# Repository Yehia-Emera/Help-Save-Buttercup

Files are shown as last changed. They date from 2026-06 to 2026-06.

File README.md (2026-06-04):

# HELP. SAVE BUTTERCUP! 🌸🫧🟢
**Automated Ball Sorting & Shooting Recycling System**

This repository contains the mechanical, electrical, and software files for our MCT231 Basics of Mechatronics final project at the Faculty of Engineering, Ain Shams University (UG2023).

## 📌 Project Overview
"Help. Save Buttercup!" is a closed-loop mechatronic system that autonomously receives, color-sorts, shoots, and recycles balls through a continuous cycle. The system integrates servo actuation, stepper motor control, IR sensing, color detection, and Bluetooth communication, all coordinated across dual Arduino Uno controllers powered by a single shared PSU.

## 🎮 The Game Theme
To make the system interactive, we integrated a Powerpuff Girls game loop. Mojo Jojo has kidnapped Buttercup, and players must help Blossom and Bubbles save her before a 2-minute timer expires. 
* Players shoot sorted balls into designated targets.
* Questions and choices appear via a Bluetooth terminal.
* **Blossom (Red Ball):** Multiplication questions. Awards 2 HP damage to Mojo Jojo on a correct answer.
* **Bubbles (Blue Ball):** Addition questions. Awards 1 HP damage on a correct answer.
* **Goal:** Deplete Mojo Jojo's 10 HP bar to win!

## ⚙️ System Architecture
The repository is organized by engineering discipline rather than subsystem, as components are shared across the dual microcontrollers.

### Hardware Specifications
* **Controllers:** 2x Arduino Uno
* **Color Detection:** TCS3200 Color Sensor
* **Sorting Actuator:** SG90 Servo (with 15g PLA+ custom claw)
* **Turnstile:** PLA+ (40mm radius, 120° sweep)
* **Shooting Base:** Stepper Motor (45° rotation)
* **Lifting Mechanism:** Servo arm (90° vertical lift over 40cm)
* **Sensors:** 5x IR Sensors (sorter, lifter x2, box x2)
* **Comms & UI:** HC-06 Bluetooth Module, 16x2 I2C LCD

## 📂 Repository Structure
* `/CAD_Assembly` - Autodesk Inventor files and 3D printable STLs (turnstile, claw, base).
* `/Code` - Arduino `.ino` files for both the master and slave controllers.
* `/Electronics` - Circuit wiring schematics and pinout diagrams.
* `/Documentation` - System flowchart, block diagram, and the final A0 presentation poster.

## 👥 Team Members
* Yehia Mohammed Fawzy (24P0322)
* Mowahed Mohamed Mohamed (24P0302)
* Ahmed Mohammed Youssef (24P0079)
* Abdulrahman Khaled Ahmed (24P0465)
* Gana Khalid Abdelwahab (24P0251)

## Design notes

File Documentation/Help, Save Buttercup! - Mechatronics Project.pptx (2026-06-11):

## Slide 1

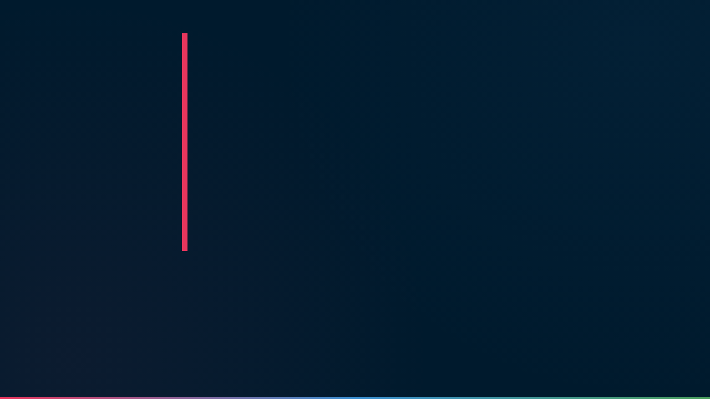
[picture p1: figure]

HELP, SAVE
BUTTERCUP!

Mechatronic Ball Sorting & Game Ecosystem

Engineering Project Defense

MCT231 · Faculty of Engineering · Ain Shams University

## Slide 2

Introduction

"Help. Save Buttercup!" is an interactive, gamified mechatronic toy that turns standard arithmetic practice into a.. physical rescue mission.

This game tackles the loss in engagement children experience when learning math through repetitive paper worksheets and assignments by transforming the process into a rewarding play experience.

Mowahed Mohamed Mohamed Mohamed 24P0302
Ahmed Mohammed Youssef Ibrahim Eidarous 24P0079 Abdulrahman Khaled Ahmed Elish 24P0465
Gana Khalid Abdelwahab 24P0251
Yehia Mohammed Fawzy Ebrahim Emera 24P0322

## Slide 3

User Research

Children in the age range from 2 to 10 years old require physical interaction to maintain focus on educational tasks; additionally, having a clear goal that lets them know what success is like minimizes frustration and off-task behaviors.

After careful considerations we decided to map specific math operations to physical ball colors (Blue for Addition, Red for Multiplication) and made a clear target goal ,that is to deplete Mojo JoJo 10 Hp Bar, to the feedback loop to maximize retention and engagement.

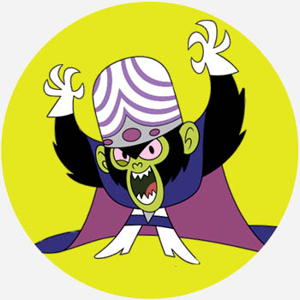
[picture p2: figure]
Mojo Jojo | Fictional Characters | Dictionary.com
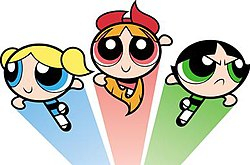
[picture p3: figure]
The Powerpuff Girls - Wikipedia

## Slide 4

Design Challenge

Engineering a fully autonomous, closed-loop mechanical system that seamlessly synchronizes with a digital educational interface, without requiring adult intervention to reset.

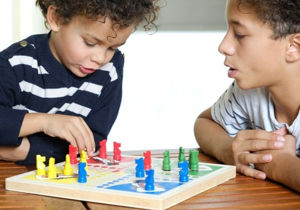
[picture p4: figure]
Educational games and toys for kids: Are they effective?

If a toy jams or requires constant manual reloading, the child's immersion breaks and the educational value is lost. A self-recycling loop ensures the user can focus entirely on the math challenges and the narrative.

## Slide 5

Toy Description and Functionality

Mojo Jojo's Hostage Situation

Townsville's toughest fighter, Buttercup, has been kidnapped by Mojo Jojo. The city's only hope lies in an automated defense system coordinated by her sisters, Blossom and Bubbles.

This project transforms a traditional mechatronic ball-sorting task into a narrative-driven game experience. Players must engage with the system to solve mathematical challenges and deplete Mojo Jojo’s health points through hardware-software synergy.

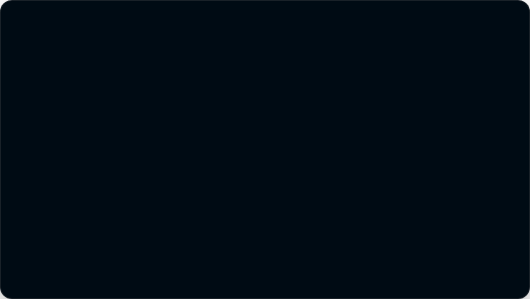
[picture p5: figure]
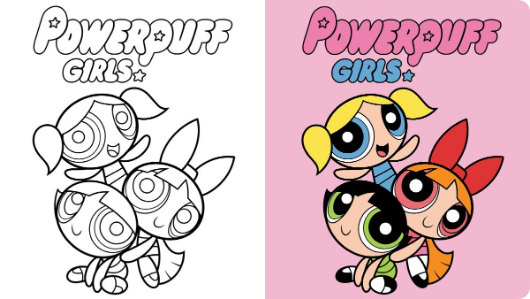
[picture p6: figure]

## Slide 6

Toy Description and Functionality

Mechanical Elements:
Intake & Sorting: A rotating turnstile regulates ball entry. An SG90 Servo actuates a custom 15g claw to physically split and route balls based on their color.
Shooting Mechanism: A stepper motor provides ±45° rotation for aiming at the target boxes, followed by a DC motor that launches the ball.
Electromechanical Support Mechanism: A high-torque servo arm acts as a vertical lifter, translating the balls 40cm upwards to automatically return them to the turnstile.

Electrical and Control Elements:
Simulated and mapped using Proteus, the system relies on a Master/Slave Dual-Arduino architecture.
Sensor System: A TCS3200 sensor detects the ball's color to trigger the correct math question. A network of 5 IR sensors tracks the ball's physical location through the turnstile, lifter, and target boxes.
Interaction: An HC-06 Bluetooth module links the physical toy's sensor data to the digital Processing game app on a desktop.

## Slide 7

THE CLOSED-LOOP ECOSYSTEM

2. Sensing

TCS3200 identifies ball color (Red/Blue).

4. Action

Stepper aims & DC motor launches ball.

1. Intake

Turnstile receives ball from return track.

3. Sorting

SG90 Claw routes ball based on color.

5. Lift

High-torque servo recycles ball to top.

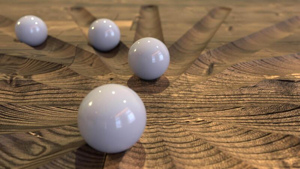
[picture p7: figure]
3D Satisfying marble balls illusion loop animation on wooden board Close up 53005331 Stock Video at Vecteezy

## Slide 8

MECHANICAL ARCHITECTURE

Ball Turnstile

40mm radius PLA+ sweep rotating 120° in 0.5s for precise intake control.

Sorter Claw

Custom made 15g claw routing balls to designated shooting reservoirs.

Shooter Base

Stepper-driven platform offering ±45° aiming precision for targets.

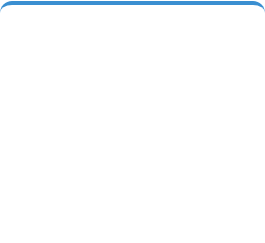
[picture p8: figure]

Vertical Lift

40cm vertical translation via high-torque servo arm recycling mechanism.

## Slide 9

SHOOTER

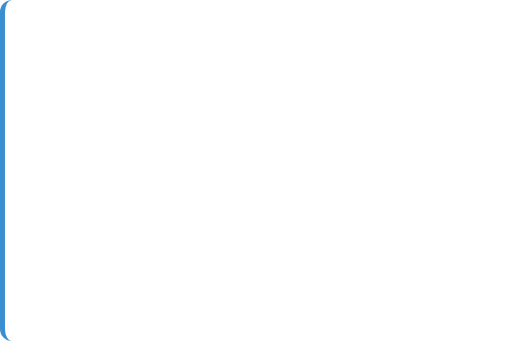
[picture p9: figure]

2048 Steps Resolution

The 28BYJ-48 Stepper Motor provides high torque and precise angular positioning (±1.8°) for the shooter base.

A high-RPM DC motor propels balls into targets, with trigger timing synchronized via the Processing app interface.

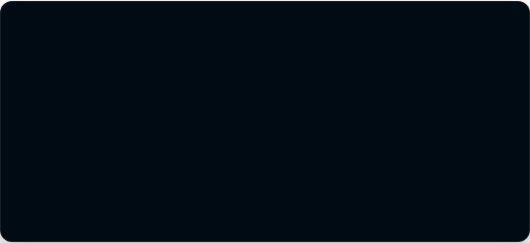
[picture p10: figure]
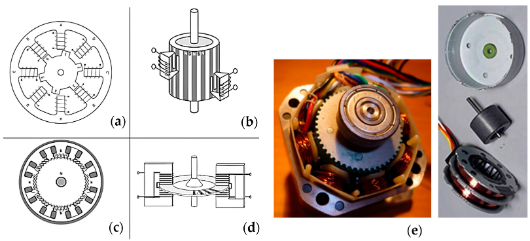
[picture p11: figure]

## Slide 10

Lifter

High-Efficiency Recycling

The system completes the closed loop by translating balls 40cm vertically back to the intake turnstile. This is achieved via a dedicated IR-triggered high-torque servo mechanism.

The integration of two IR sensors (at the base and top) ensures the motor only actuates when a ball is present.

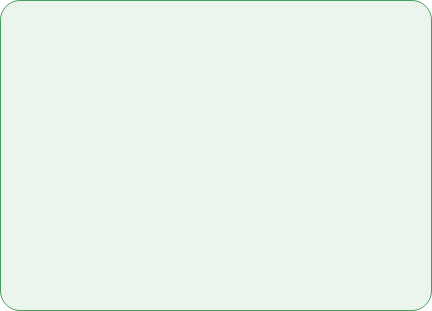
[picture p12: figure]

40cm

Lifting Height

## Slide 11

Game Logic

Blossom (Red Ball) Multiplication prompts. Success deals -2 HP damage to Mojo Jojo. Higher difficulty, higher reward.

Bubbles (Blue Ball) Addition prompts. Success deals -1 HP damage. Reliable and steady progress toward the goal.

Winning State 10 HP boss bar tracking. Real-time feedback on 16x2 LCD and Processing UI upon Mojo Jojo's defeat.

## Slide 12

Prototyping and Iteration

- The physical build utilized PLA+ printed parts, Wooden parts manufactured by laser cutting, standard servos, and a unified 12V power supply.
- There were several iterations to the lifting mechanism in our project; at the start it was a conveyor belt but midway through we realized that it was hard to implement at our skill level and knowledge.
- After that we used a lifting arm with a servo motor. After some trials we realized that the mechanical connections holding the servo motor and the arm were not applicable so finally we changed it to our current mechanism

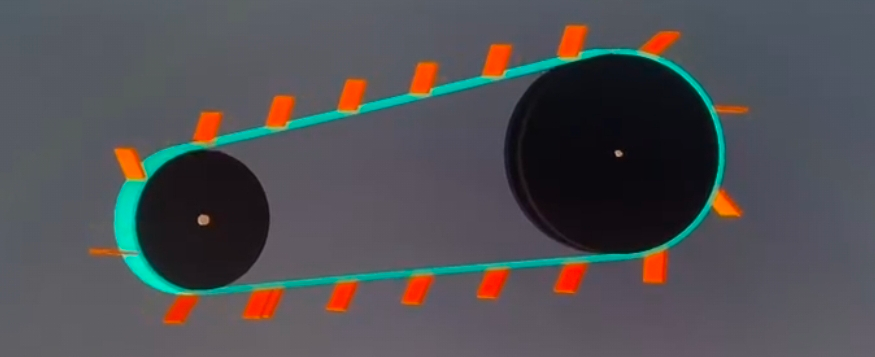
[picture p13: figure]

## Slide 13

Safety Considerations

Low Voltage: The entire toy operates on a closed 12V DC power supply which isn’t dangerous even if it was in direct contact with a person
Enclosed Mechanisms: The DC shooting motors and high-torque lifter servos are housed within the chassis to prevent the small fingers from being pinched.
Sharp edges : There aren’t any sharp edges present in the project
Material Safety: Constructed with non-toxic PLA+.

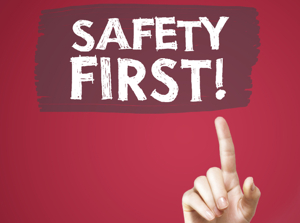
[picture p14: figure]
Safety considerations for chemicals

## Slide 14

Educational Impact

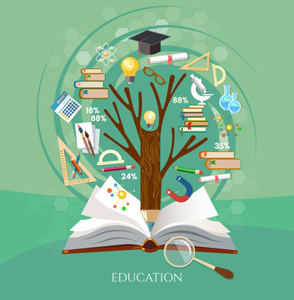
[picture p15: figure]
Education tree illustration

Educational Benefits: The toy dynamically adapts to the physical ball sorted, directly tying tactile play to cognitive math development.
Skill Development:
Blue Balls (Bubbles): Triggers foundational Addition equations. Success builds math confidence and deals 1 HP of damage to Mojo jojo.
Red Balls (Blossom): Triggers Multiplication equations, for a higher reward of 2 HP damage.

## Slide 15

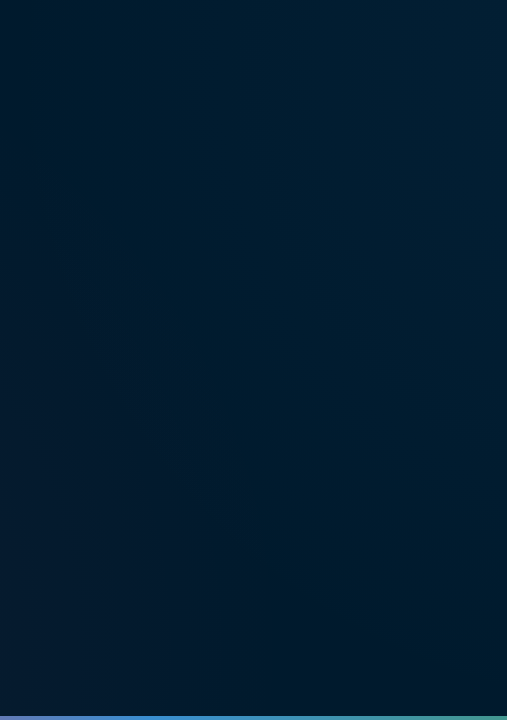
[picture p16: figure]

Final Product

- The child inserts a ball into the system. The digital UI displays a math challenge based on the ball's color; finally, the child aims at the right or left directions and shoots to register that number as his answer.
- the app deducts health from Mojo Jojo's 10 HP bar, and the electromechanical lift auto-recycles the ball for continuous play.

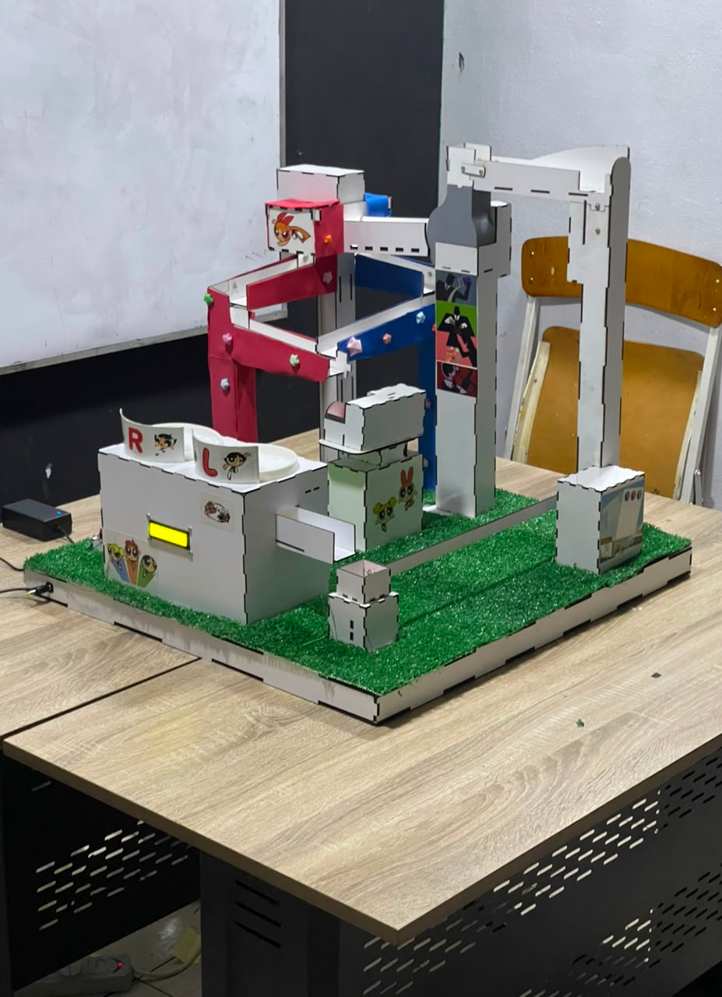
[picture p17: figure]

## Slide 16

Conclusion

To summarize, "Help. Save Buttercup!" successfully bridges the gap between mechatronic engineering and early childhood education.
By automating the reset process and tying physical accuracy to a digital narrative, we have proven that foundational math practice can be as thrilling as defeating a supervillain.

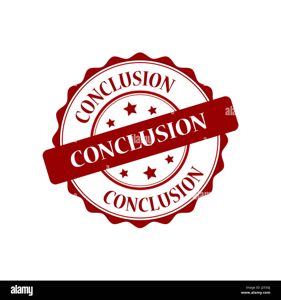
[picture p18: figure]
Conclusion vectors hi-res stock photography and images - Alamy

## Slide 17

Thank you for your attention. We are ready to discuss the mechanical, electrical, and software nuances of our automated ball sorting ecosystem.

Q&A

Buttercup is Saved!

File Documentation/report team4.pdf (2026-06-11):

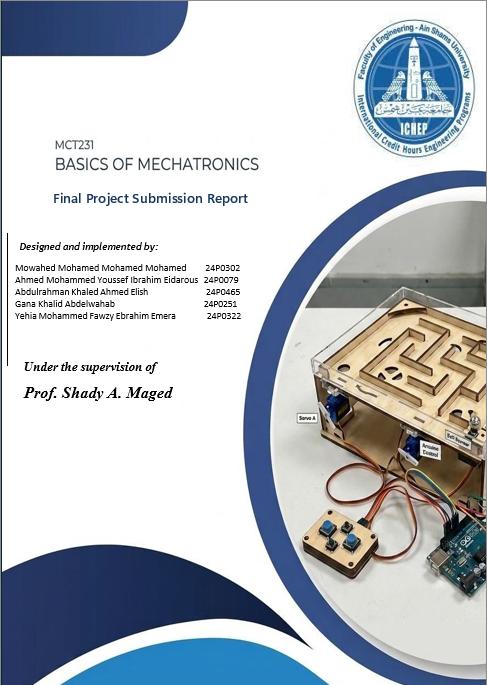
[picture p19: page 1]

## Table of Contents

## List of figures

## Introduction:

Designing and developing a mechatronic system requires the effective integration of mechanical design, electronics, and software control into a unified and functional solution. This Major Task project reflects the application of core engineering principles and practical skills acquired throughout the course, with a focus on hands-on development, system integration, and iterative

prototyping.

The main objective of the project is to conceptualize and implement a complete system that performs a defined function reliably and efficiently. The development process follows a structured design methodology, beginning with problem identification and requirement analysis, followed by concept generation, detailed design, prototyping, and final implementation. The system incorporates key subsystems such as actuation mechanisms, embedded control units, and sensing components working together to achieve the desired

performance.

The project brings together multiple engineering domains,

### including microcontroller programming, electronic circuit design and PCB development, mechanical modeling and assembly, and system simulation. User interaction and communication interfaces are also considered to enhance system control, monitoring, and

feedback.

### All stages of the design and development process are presented, including the reasoning behind major decisions, testing

and validation procedures, and performance evaluation.

### Challenges encountered during implementation are discussed along with the solutions applied, ensuring that the final system meets functional requirements as well as relevant engineering

and safety standards.

## Work Break Structure (WBS):

1 Project Initiation

| 1.1 | Project Planning
| | 1.1.1 | Gantt Chart Creation
| | 1.1.2 | Defining deliverables

2 Mechanical Design

| 2.1 | Designing the mechanisms
| | 2.1.1 | Sorting mechanism
| | 2.1.2 | Vertical lifting mechanism
| | 2.1.3 | Projectile mechanism
| | | 2.1.3.1 | Projectile calculations
| 2.2 | Actuator Sizing
| | 2.2.1 | Torque/Force calculations
| | 2.2.2 | Motor/Servo selection
| 2.3 | Fully integrated CAD Design

3 Coding

| 3.1 | Mechanical logic coding
| 3.2 | Electrical logic coding

4 Electrical and Control Design

| 4.1 | Microcontroller integration
| 4.2 | Sensor integration
| 4.3 | User interface design
| | 5.3.1 | LCD display
| | 5.3.2 | Interactive mobile app
| 4.4 | PCB design
| 4.5 | Wiring and connections

5 Prototyping and Testing

| 5.1 | Prototype assembly
| 5.2 | Testing
| 5.3 | Iterations

## Gantt Chart

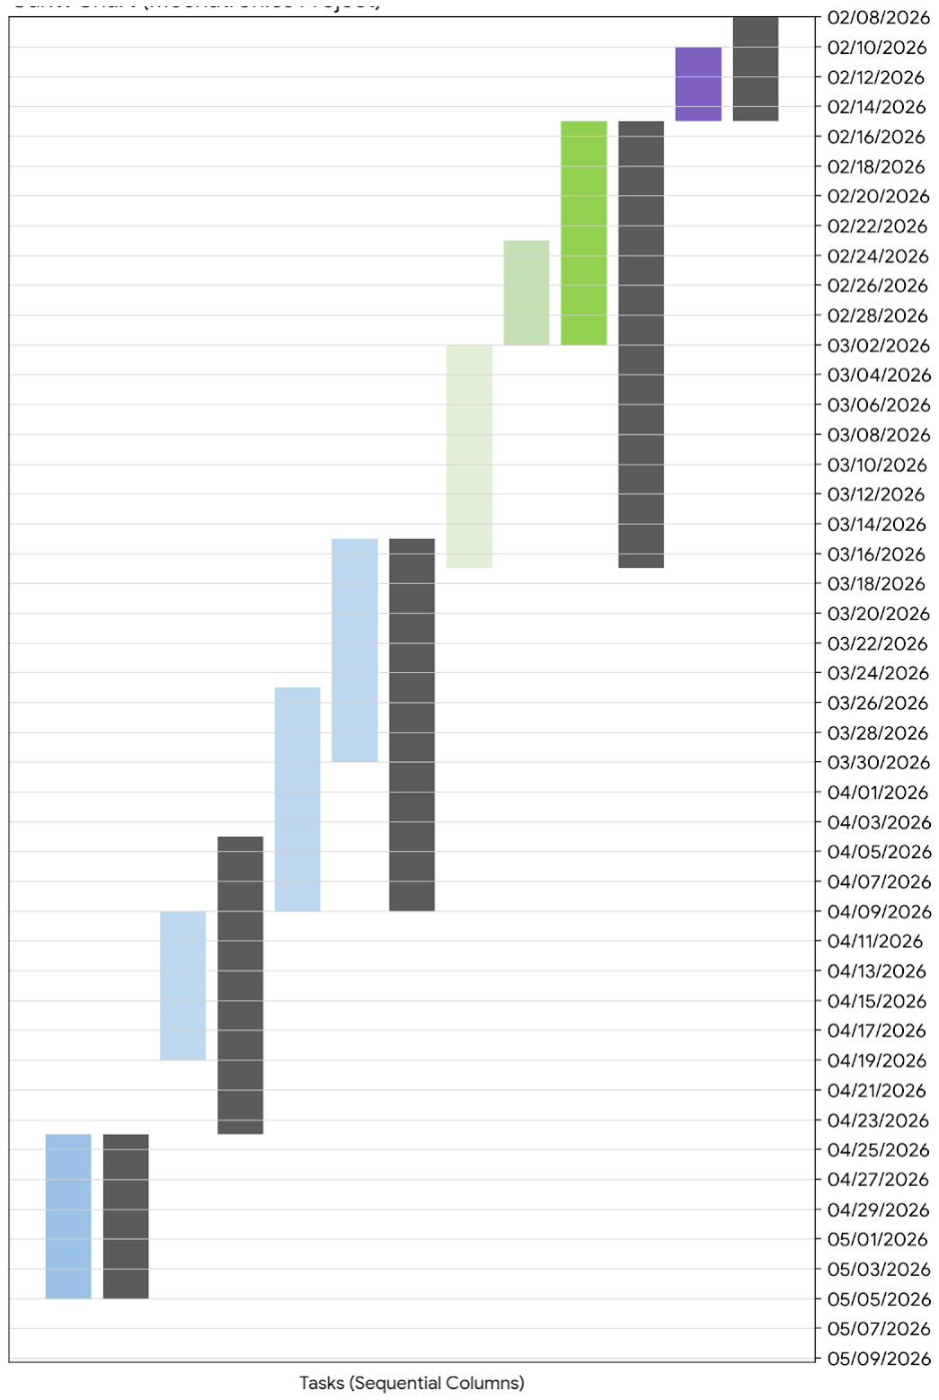
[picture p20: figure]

Figure 1 Gantt Chart

## Project Design Specification (PDS)

## 1. Introduction

### “Help. Save Buttercup!” is a machine that automatically lifts, sorts, and shoots a ball at targets chosen by the user. It works in a continuous loop, using sensors and

motors to keep the ball moving without needing someone to manually reset it.

## 2. Basics Operation

### First, a turnstile drops one ball at a time into a color sorter. A servo motor then guides the ball toward one of two distinct paths based on its color that lead to a ball

shooter. Next, the user gives a command to shoot the ball at one of two targets. After the ball hits a target, it rolls to an arm lifter. A sensor sees the ball and turns on a motor to lift it back to the top turnstile. The cycle then starts all over again.

## 3. Scope

### - Intentions & Audience: This machine is a sophomore-level project for the Basics of Mechatronics course at Ain Shams University. It is built to show how sensors, coding, and moving parts work together in a continuous loop. The

Audience is from 8-10 years of age.

### - Restrictions: The design is limited to using only two Arduinos and one power

supply. It also needs to be finished before the semester ends.

## 4. Functional Requirements

a) Construction
Key Consideration | Requirements | Issues/Challenges
Materials and process | • 3D printed plastic (PLA) for the ball turnstile, sorter gates, and custom mounts. • Acrylic or wood (MDF) for the main frame and tracks. •DC motor for the shooter mechanism. • Processes: 3D printing, laser cutting, and manual assembly. | • 3D printed parts must have precise tolerances, so the ball doesn't get stuck. • The DC motor must be strong enough to shoot the ball, but not so strong that it breaks the wood mounts.
Dimensions and weight | • Height: Max 60 cm • Width: Max 1m • Length:Max 1m • Weight: Max 10kg | • The entire machine must fit inside the 1m by 1m square footprint.
Quantity | Initial production of 1 working prototype unit. | Since you are only building one machine, if a custom part breaks during testing, the team has to stop working to make a new one.
Lifespan/ ReliabilityThe project is expected to work correctly for 1 | year (to survive grading and testing). • It must run smoothly in a continuous loop without the ball jamming. | • The single power supply and the two Arduinos might get hot if you run the loop for too long without a break. • Wires can easily vibrate loose while the motors are running.
Maintenance | • Check all wire connections before turning the power on. • Wipe dust off the color and IR sensors so they read correctly. | • If you pack all the parts too tightly inside the 1m by 1m space, it will be hard to reach your hands inside to fix a broken wire or clean a sensor.
Power consumption | Total required ampere by the system = 4080mA Power consumption for the entire system= 24.04W A 12V 3A power supply will be used to power the machine | The entire system must be power with a single power supply

b) Experience
Key Consideration | Requirements | Issues/Challenges
Aesthetics | • The machine should have a clean, organized look with neatly tied wiring (good cable management). • Different sections (Sorter, Shooter, Lifter) should be color-coded to match the theme | • Keeping all the wires from the two Arduinos and the shared power supply tidy without making them too hard to reach for repairs.
Ergonomics | • The controls (buttons or mobile interface) used to select a target and shoot must be clearly labeled and easy to press. • The LCD screen displaying the score from the IR sensors must be positioned at an easy-to-read angle. | • Making sure there is no noticeable delay between the user pressing the "shoot" button and the motor actually firing the ball. • Placing the user controls in a safe spot away from the moving turnstile.

c) Safety
Key Consideration | Requirements | Issues/Challenges
Safety considerations | • Moving parts like the lifter's arm, the turnstile, and the shooter's can pinch fingers . • The shooter mechanism could accidentally fire the ball over the 60 cm height limit or outside the machine. • The shared power supply and DC motors could overheat during continuous loops. | • Making sure users and teammates keep their hands out of the 1m by 1m area while the system is powered on.
Safety standards | • All wiring between the two Arduinos, sensors, and motors must be fully covered (insulated) to prevent short circuits . • The system must run entirely on low-voltage DC power. | • Designing covers for the moving parts that protect the user, but still allow you to see the ball moving through the sorter and lifter.
Testing | • Run the power supply and motors for a continuous 10-minute loop to check for overheating before the final presentation. • Test-fire the shooting mechanism at least 20 times to ensure the ball always hits the IR targets and never flies out of bounds. | • Safely testing the maximum force of the shooter's DC motor without breaking the 3D-printed parts or the targets.
d) Transport
Key Consideration | Requirements | Issues/Challenges
Packaging | • The machine must be built on a solid, rigid base (like thick wood) so the frame does not bend when you pick it up. | • A 1m by 1m board is quite wide, making it tricky to carry through standard doorways without bumping the edges.

| • Sensitive parts like the Arduinos, LCD screen, and sensors should be taped down or covered so they don't get crushed. | • The 60 cm height means the lifter or shooter might catch on things if not careful.
Shipping | • The project must fit into the back seat or trunk of a standard car or SUV to be transported to the university lab. • It needs to be carried flat to keep the balls from falling out of the tracks. | • Bumps during the car ride could easily shake the Arduino wires loose or mess up the exact 110° alignment of the turnstile servo.
e) Environmental
Key Consideration | Requirements | Issues/Challenges
Recycling | • At least 80% of the electronic parts (the 2 Arduinos, servos, DC motors, LCD, and sensors) must be easily removable to be reused in future projects. • The main 1m x 1m base should be kept intact for another team or project if possible. | • If you use too much hot glue or permanent adhesive to attach the motors and sensors, you might break them when trying to take the machine apart.
Disposal | • Any broken wires, burnt-out components, or damaged batteries must be thrown away in designated electronic waste (e-waste) bins. • Broken 3D-printed plastic parts can be thrown in the standard trash. | • Making sure the team actually takes the time to unscrew and save the parts after grading, rather than just throwing the whole 1m by 1m board in the dumpster.

## Fully Integrated System

## 1. CAD Design

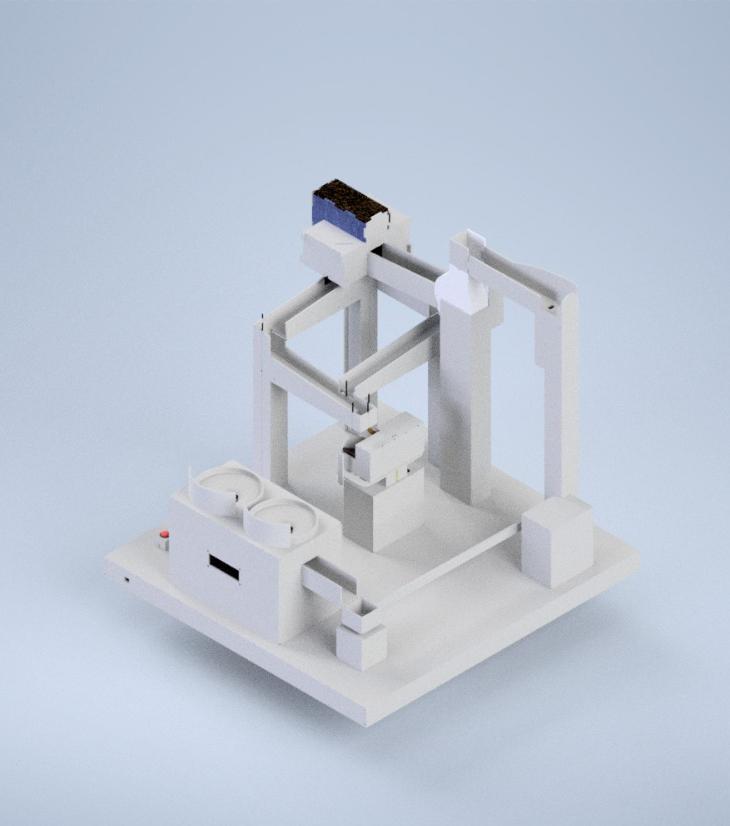
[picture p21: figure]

Figure 2 Fully Integrated CAD design

## 2. Wiring Diagram

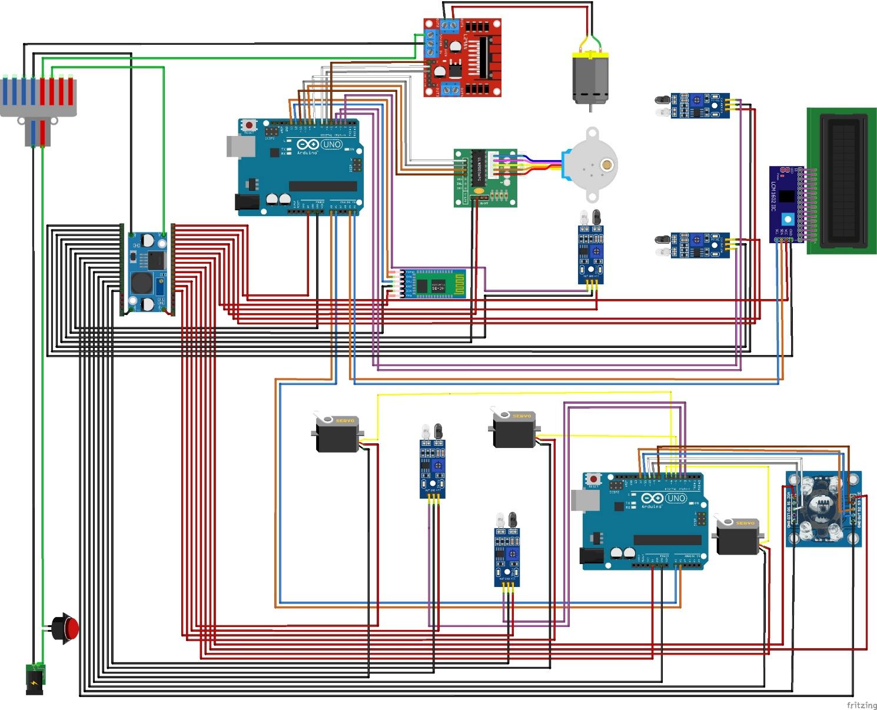
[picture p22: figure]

Figure 3 Fully integrated Wiring Diagram

## 3. Block Diagram

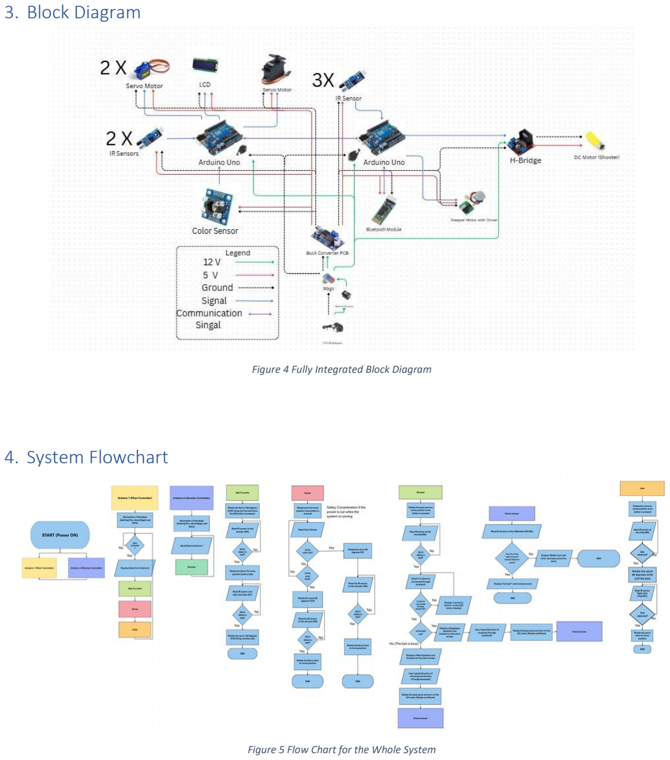
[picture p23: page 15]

Figure 4 Fully Integrated Block Diagram

## 4. System Flowchart

Figure 5 Flow Chart for the Whole System

## 5. Hardware Implementation

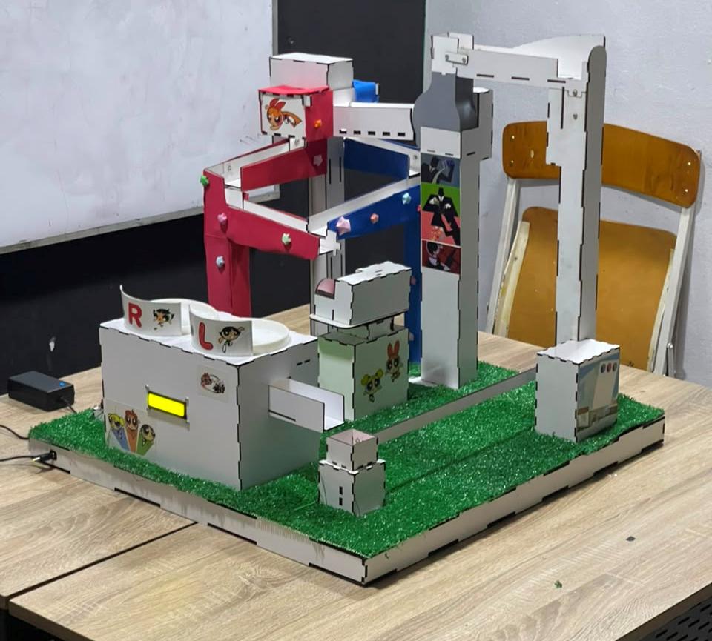
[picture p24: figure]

## 6. Arduino Code

### The entire system code can be found on the GitHub repository attached below:

### 7. PCB


The above PCB was used to distribute a voltage of 5V on various components using a buck converter.

### The converter steps down the voltage from 12V received by the supply to 5v that is more

manageable for most electronic devices. Ewe attached terminal blocks in the pin holes on the PCB for

### a more professional wire management

## 8. Processing I/O user interface

### We made a user interface that controlling the shooting mechanism via Bluetooth to add an

interactive feature to the game.

## 9. LCD


The LCD on the shooter box serves as an HP meter for the game, where you win by dealing damage through the I/O interactive feature.

## Sorting Mechanism

## 1. CAD design


### 2. Block Diagram

## 3. Wiring Diagram


## 4. Flowchart


## 5. Actuator sizing


## Lifting Mechanism

## 1. CAD Design


## 2. Wiring Diagram

## 3. Flowchart

## 4. Actuator Sizing


## Shooting mechanism

## 1. CAD Design


## 2. Block Diagram


## 3. Wiring Diagram

## 4. Flowchart

## 5. Projectile Calculations:

a) Problem Statement:

A DC motor with an arm shoots a 6 grams ball with the following conditions:

Projectile specs:

- Initial Height (y◦): 3.9 cm (0.039 m) (from the base of the motor)
- Horizontal Distance (x): 23 cm (0.23 m)
- Time of Flight (ttotal): 0.27s
- Lauch Angle (θ): 30◦
- Ball mass (mball): 6g (0.006

kg) Arm specs:

- Length (L): 3.6 cm (0.036 m)
- Mass (marm ): 1 g (0.001 kg)
b) Objectives:
- Determine initial velocity (Vx , Vy ) of the ball.
- Calculate maximum height (H ).
- Compute force applied by the arms (Favg ), and needed Torque (Tavg).
- Acceleration Components (Ax , Ay).

0.19

c) Step-by-Step Calculations:

1.1 Initial Velocity Components (Vx , Vy)
The ball moves horizontally 0.23 m in 0.27 s before reaching the datum (the base of the motor)
a) Horizontal Velocity (Vx):
X = Vx ∗ t
b) Vertical Velocity (Vy):

X
Vx =
t

0.23
=
0.19

≈ 1.2 m/s

y = y0 + Vy

∗ t −

1
(gt²)
2

Vy

0 = 0.039 + Vy ∗ 0.19 − (. 5 ∗ 9.81 ∗ (0.19)

2)

=

((0.5 ∗ 9.81 ∗ (0.19)²) − 0.039)⁄ ≈ 0.72m/s

c) Total Initial Velocity (V):

V = √Vx
2 + Vy

2 = √1.2² + 0.72² ≈ 1.4 m/s

d) Launch Angle (θ):
θ = tan⁻¹(

Vy
⁄ ) = tan⁻¹(

. 72⁄ ) ≈ 30.9°
(Expected 30)

1.2 Maximum Height (H):

a) Time to Reach H (tup):
Vx | 1.2

Vyat H = Vy − g ∗ tup

tup =

b) Calculating H:

Vy − 0
=
g

0.72
≈ 0.073 s
9.81

H = y° + Vy ∗ tup − (0.5 ∗ g ∗ tup2)

H = 0.039 + 0.72 ∗ 0.073 − (. 5 ∗ 9.81 ∗ (0.073)

2) ≈ 0.065m ≈ 6.5cm

1.3 Torque Applied by Arm (Impulse)

a) Impulse (J):
J = ∆P = mball ∗ V = 0.006 ∗ 1.4 = 8.4 x 10⁻³ Kg. m/s
b) Average Force (Favg):

Favg =

J
=
∆t

. 0084
= 0.84 N
0.01
c) Calculating Torque (Tavg):
T = Favg ∗ L = 0.84 ∗ 0.036 = 0.03 N. m

1.4 Acceleration Components (Ax , Ay):

a) Average Acceleration (Aavg): Favg = mball ∗ Aavg

Aavg

Favg
=
mball

. 84
=
0.006

≈ 140 m/s
2
b) Acceleration Components (Ax, Ay):
Ax = Aavgsin(θ) = 140 ∗ cos(30.9) = 120.1 m/s
2

Ay = Aavgcos(θ) = 140 ∗ sin(30.9) = 71.9 m/s
2

d) Summary of Results:
Horizontal Velocity (Vx) | 1.2 m/s
Vertical Velocity (Vy) | 0.72m/s
Total Initial Velocity (V° ) | 1.4 m/s
Launch Angle (θ) | 30.9° (Expected 30)
Maximum Height (H) | 6.5cm
Average Force (Favg) | 0.84 N
Horizontal Acceleration Ax | 120.1 m/s²
Vertical Acceleration Ay | 71.9 m/s²

Figure 15, Summary of Results

## 6. Actuator Sizing:

a) Problem Statement:
a) Using a PM DC motor, it needs to launch a 6 g ball for 23 cm, what is the specs of the needed DC motor.
b) Using a Stepper motor, we need to rotate a 150 g base of the shooter for certain angles, what are the specs of the needed stepper motor
b) Objectives:
1. Determine the needed torque for launching the ball.
2. Select the DC motor.
3. Determine the needed torque for rotating the base.
4. Select the Stepper motor.
c) Step by Step Sizing:

1.1 Calculating needed torque for launching the ball (Treq):

# Treq = (J ∗ θ°°) + Tres

a) Calculating Inertia Effective (Jeff): Jeff = Jload + Jmotor
Let Jmotor = Jload | → Jeff = 2 * Jload
| Jload = Jorigin = Jarm + md²
(Using Parallel Axis Theorem)

Figure 16, The arm

Note: Knowing the Arm Inertia (Jarm) Using the software used to design the arm (Autodesk Inventor)\

And the COG to determine the distance between the COG of the arm and the Origin

Figure 18, Shooter Arm COG | Figure 17, Shooter Arm Inertia

So, we got this Ixx = 0.176 Kg.mm² = 1.76 x 10⁻⁵ kg.m²
,

d = √y2 + z2 = √(−0. 305)
2 + (−9. 023)

2 ≈ 9. 028 mm = 0.009028 m

Jload = Jarm + md² = 1.76 ∗ 10⁻⁵ + 0.006 ∗ (.009028)² ≈ 1.8 ∗ 10⁻⁵ Kg. m²

Jeff = 2 ∗ Jload = 2 ∗ 1. 8 ∗ 10⁻5 = 3. 6 ∗ 10⁻5 kg. m2

Form 3.1 section we got the initial velocity of 1.4 m/s

So we can calculate the angular velocity (ωlauncℎ) form the equation:

ωlauncℎ =

V°
=
r

1.4
= 38.88 rad/s
0.036

Then we can build the motion profile according to ωlauncℎ


Figure 19, Trapezoidal Motion Profile of DC Motor

Where tacc = 0.15s,tconstant = 0.70s, tdecc = 0.15s, and tdwell = 0.1s.

Then we calculate the angular acceleration (θ°°):


Figure 20, Acceleration Diagram of DC Motor.
θ°°acc = αacc ≈ 259. 253 rad/s2

θ

°°
const = αconst = 0 rad/s

2

θ°°decc = αdecc ≈ −259.253 rad/s
2

Note: The Tres is neglectable, so we will consider it in the safety factor.

Now, We can calculate the Torque Required (Treq):

Treq = (Jeff ∗ θ

°°)

(Treq)acc = 3. 6 ∗ 10⁻5 ∗ 259. 253 ≈ 0. 0093 N. m = Tpeak

(Treq)const = 3. 6 ∗ 10⁻5 ∗ 0 ≈ 0N. m

(Treq)decc = 3. 6 ∗ 10⁻5 ∗ −259. 253 ≈ −0. 0093 N. m

Trms

= √

((Treq)acc

2
∗ tacc) + ((Treq)const

2
∗ tconst) + ((Treq)decc

2
∗ tdecc) + ((Treq)dw

2
∗ tdw)

tacc + tconst + tdecc + tdw

### (0.0093² ∗ 0.15) + (0² ∗ 0.7) + (−0. 0093² ∗ 0.15) + (0² ∗ 0.1)

= √
0.15 + 0.7 + 0.15 + 0.1
≈ 0. 00486 N. m

1.2 Select the DC motor:
We got that (Treq)peak = 0. 0093 N. m & Trms = 0.00486 N. m

### After multiplying at n=20 as a safety factor because we neglected the resistance torque (Tres) we need a DC motor with Torque of 0.186 N.m

### We found that the M1-1-Q1-DC-Motor-4WD can be used on its maximum torque at 12V and it is equal

0.3 N.m

### Knowing that the motor will not work at 100% efficiency so let assume η = 0.6

### So the generated torque will be 0.18 N.m which is

enough for out application.

1.3 Calculating needed torque for rotating the base (Treq):

# Treq = (J ∗ θ°°) + Tres

a) Calculating Inertia Effective (Jeff): Jeff = Jload + Jmotor


Figure 21, M1-1-Ǫ1-DC-Motor-4WD

Let Jmotor = Jload | → Jeff = 2 * Jload
| Jload = Jorigin = Jbase + md²
(Using Parallel Axis Theorem)

As shown in figure 22, the base has 14 items on it so it will be a long process to compute the inertia of each component so for simplifying we will represent the base and its components as a cylinder with the outer dimensions of the base which are d =
75 mm, and L = 150 mm

Knowing that the mass of the base with the components is 150 gm

So, we got this I = 1.05 x 10⁻⁴ kg.m²
,


Figure 22, the base & all parts on it

The COG of the cylinder is be above the shaft of the motor with the radius of the cylinder so d = 75/2 mm = 0.0375 mm

Jload = Jbase + md² = 1.05 ∗ 10⁻⁴ + 0.15 ∗ (0.0375)² ≈ 3.16 ∗ 10⁻⁴ Kg. m²

Jeff = 2 ∗ Jload = 2 ∗ 3. 16 ∗ 10⁻3 = 6. 3 ∗ 10⁻4 kg. m2

We have set the speed of the stepper motor in the code to 10 rpm

So we can calculate the angular velocity (ωrotating) form the equation:

ωrotaing =

2π ∗ RPM
=
60

2π ∗ 10
= 1.047 rad/s
60

Then we can build the motion profile according to ωrotating


Figure 23, Trapezoidal Motion Profile of Stepper Motor
Where tacc = 0.25 s,tconstant = 1.0 s,tdecc = 0.25 s, and tdwell = 0.1s

Then we calculate the angular acceleration (θ°°):


Figure 24, Acceleration Diagram of Stepper Motor.
θ°°acc = αacc ≈ 4. 16 rad/s2

θ

°°
const = αconst = 0 rad/s

2

θ°°decc = αdecc ≈ −4.16 rad/s
2

Note: The Tres is neglectable, so we will consider it in the safety factor.

Now, We can calculate the Torque Required (Treq):

Treq = (Jeff ∗ θ

°°)

(Treq)acc = 6. 3 ∗ 10⁻4 ∗ 4. 16 ≈ 0. 0026 N. m = Tpeak

(Treq)const = 6. 3 ∗ 10⁻4 ∗ 0 ≈ 0N. m

(Treq)decc = 6. 3 ∗ 10⁻4 ∗ −4. 16 ≈ −0. 0026 N. m

Trms

= √

((Treq)acc

2
∗ tacc) + ((Treq)const

2
∗ tconst) + ((Treq)decc

2
∗ tdecc) + ((Treq)dw

2
∗ tdw)

tacc + tconst + tdecc + tdw

### (0. 0026² ∗ 0.25) + (0² ∗ 1.0) + (−0. 0026² ∗ 0.25) + (0² ∗ 0.1)

= √
0.25 + 1.0 + 0.25 + 0.1
≈ 0. 00145 N. m

### 1.4 State the Stepper motor:

We got that (Treq)peak = 0. 0026 N. m & Trms = 00145 N. m


### We found that the 28-BYJ-48 Stepper motor When it works on 12V it can Provide up to 0.0043 N.m Which is more than enough for our application and we can consider the excess in torque as safety factor

n = 2.

## Conclusion

### The successful completion of this major task served as a comprehensive application of mechatronics engineering fundamentals, bridging the gap between theoretical

design and physical implementation. By integrating mechanical design, electronics,

### and embedded programming, we developed a functional automated system capable

of precise ball detection and launching.

### Throughout the project, several key milestones were achieved:

### - Mechanical Synthesis: Using Autodesk Inventor, we designed and simulated a snap-motion rack-and-pinion mechanism, ensuring that the mechanical components could withstand the required stresses while maintaining smooth

motion.

### - Hardware Integration: The system utilized an Arduino-based control unit paired with IR sensors for real-time feedback, demonstrating the importance of

sensor accuracy in autonomous systems.

### - Fabrication Excellence: The transition from CAD to reality involved 3D printing and laser cutting, where we learned to account for material tolerances and the

effective use of mechanical fasteners like M3 screws and heat-set inserts.

### Ultimately, this project reinforced the necessity of a multidisciplinary approach. It provided invaluable experience in troubleshooting complex electromechanical interfaces and refined our ability to manage a project from the initial concept phase

through to a fully realized, integrated prototype.

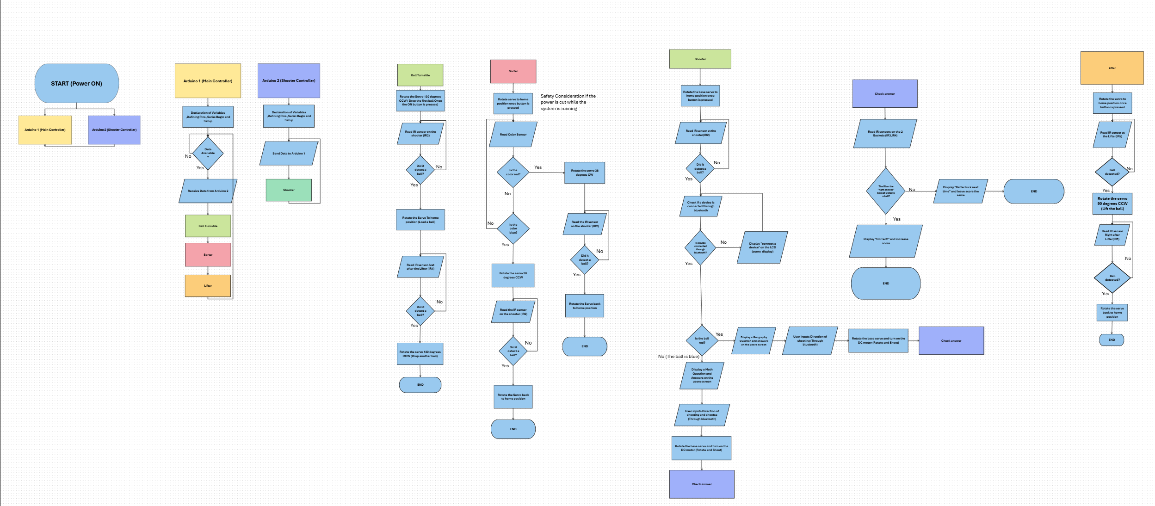
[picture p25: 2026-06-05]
Documentation/FlowChart.png

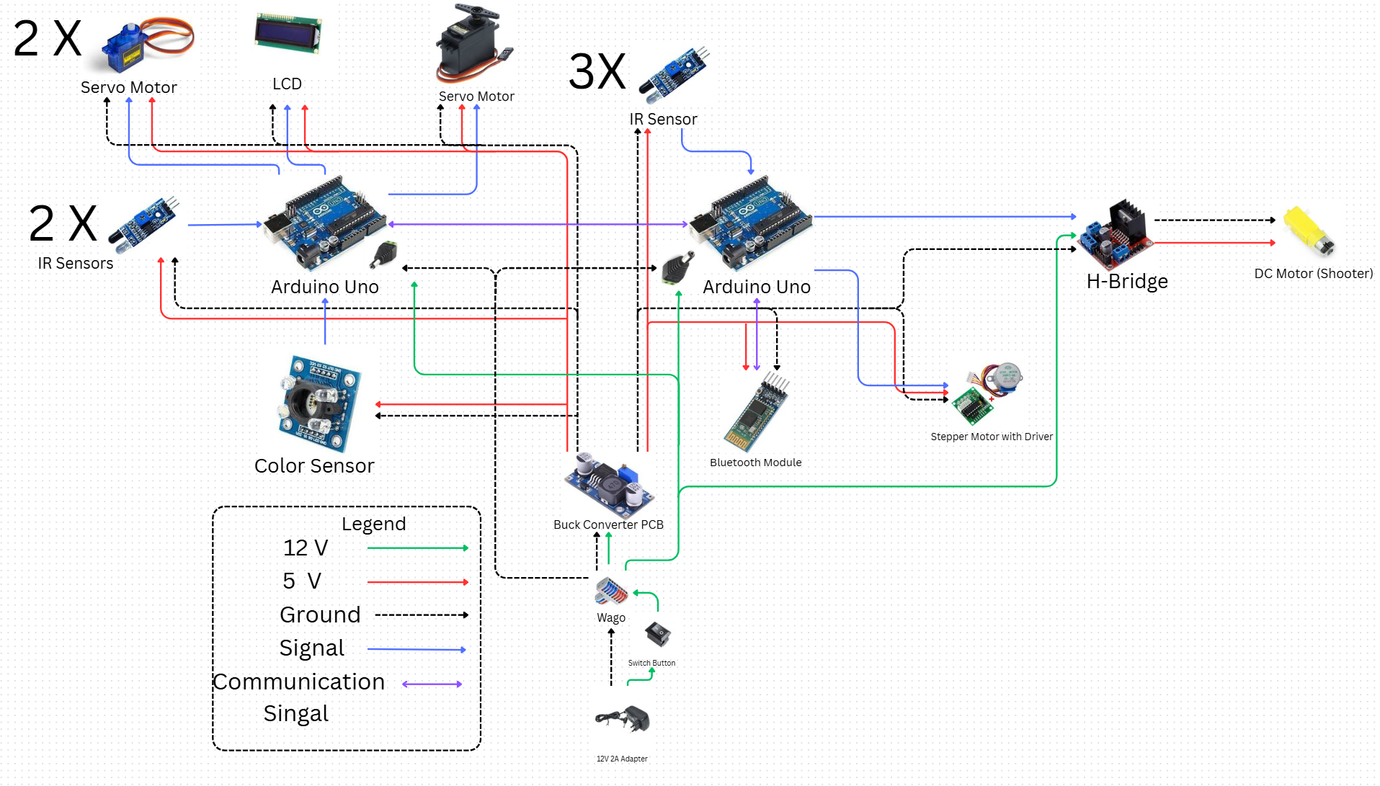
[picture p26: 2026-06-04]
Documentation/Block Diagram.png

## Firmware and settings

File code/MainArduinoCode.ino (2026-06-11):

#include <Servo.h>
#include <SoftwareSerial.h>

SoftwareSerial ShooterComm(A0, A1);

//=============Color Sensor Pin definitions and Variable Declaration==================
#define Sorting_Servo_Pin 7
#define S0 10                    
#define S1 9                     
#define S2 12                    
#define S3 8                     
#define Color_Sensor_Output 11   

Servo Sorter_Servo;
const int sorterServoHomeAngle = 90;
const int sorterServoBlueAngle = (45 - 7);
const int sorterServoRedAngle = (135 + 7);

uint8_t Frequency = 0;
uint8_t Color = 0;
uint8_t R = 0;
uint8_t G = 0;
uint8_t B = 0;

uint8_t lastColorState = 0;

//============Lifter and Turnstile Pin definitions and Variable Declaration==================
#define Lifter_Servo_Pin 5
#define Turnstile_Servo_Pin 6
#define At_Lifter_IR_Sensor 3
#define After_Lifter_IR_Sensor 4

Servo Lifter_Servo;
Servo Turnstile_Servo;

const int LifterHomeAngle = 16;
const int LifterTopAngle = (110);

const int TurnstileHomeAngle = 0;
const int Turnstile_Out_Angle = (125);

int Colour_Read(); 

void setup() {
  pinMode(S0, OUTPUT);
  pinMode(S1, OUTPUT);
  pinMode(S2, OUTPUT);
  pinMode(S3, OUTPUT);
  pinMode(Color_Sensor_Output, INPUT);

  Sorter_Servo.attach(Sorting_Servo_Pin);

  digitalWrite(S0, HIGH);
  digitalWrite(S1, LOW);

  Serial.begin(9600);
  ShooterComm.begin(9600);  

  pinMode(At_Lifter_IR_Sensor, INPUT);
  pinMode(After_Lifter_IR_Sensor, INPUT);
  Lifter_Servo.attach(Lifter_Servo_Pin);
  Turnstile_Servo.attach(Turnstile_Servo_Pin);

  Sorter_Servo.write(sorterServoHomeAngle);
  Lifter_Servo.write(LifterHomeAngle);
  Turnstile_Servo.write(Turnstile_Out_Angle);
}

void loop() {
  Colour_Read();

  switch (Color) {
    case 1:
      Sorter_Servo.write(sorterServoBlueAngle);
      break;

    case 2:
      Sorter_Servo.write(sorterServoRedAngle);
      break;

    default:
      break;
  }

  // Handle incoming data requests from Shooter Arduino
  if (ShooterComm.available()) {
    char receivedChar = ShooterComm.read();
    
    // If shooter sends Homing / IR Sensor status updates
    if (receivedChar == '0' || receivedChar == '1') {
      bool shooterIRSensorState = (receivedChar == '1'); 
      
      Serial.print("Shooter IR: ");
      Serial.println(shooterIRSensorState); 
      
      if (!shooterIRSensorState) { 
        Sorter_Servo.write(sorterServoHomeAngle);
        Turnstile_Servo.write(TurnstileHomeAngle);
      }
    } 
    // If shooter requests current Color status
    else if (receivedChar == '?') {
      ShooterComm.print(Color); // Immediately reply with the raw color status (0, 1, or 2)
    }
  }

  //=============Lifter and Turnstile Code===================
  if (digitalRead(At_Lifter_IR_Sensor) == LOW) {
    Lifter_Servo.write(LifterTopAngle);
  }
  if (digitalRead(After_Lifter_IR_Sensor) == LOW) {
    Lifter_Servo.write(LifterHomeAngle);
    Turnstile_Servo.write(Turnstile_Out_Angle);
  }
}

//==========Sorter Function===============
int Colour_Read() {
  digitalWrite(S2, LOW);
  digitalWrite(S3, LOW);
  Frequency = pulseIn(Color_Sensor_Output, LOW);
  R = Frequency;

  digitalWrite(S2, HIGH);
  digitalWrite(S3, HIGH);
  Frequency = pulseIn(Color_Sensor_Output, LOW);
  G = Frequency;

  digitalWrite(S2, LOW);
  digitalWrite(S3, HIGH);
  Frequency = pulseIn(Color_Sensor_Output, LOW);
  B = Frequency;

  if (70 < R && R < 130 && 165 < G && G < 230 && 130 < B && B < 190) {
    Color = 1;  // Red
  } else if (165 < R && R < 225 && 140 < G && G < 200 && 100 < B && B < 150) {
    Color = 2;  // Blue
  } else {
    Color = 0;  // Unknown/No ball
  }
  return Color;
}

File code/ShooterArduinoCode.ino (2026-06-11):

#include <Stepper.h>
#include <SoftwareSerial.h>
#include <Wire.h>
#include <LiquidCrystal_I2C.h>

LiquidCrystal_I2C lcd(0x27, 16, 2);

SoftwareSerial BT(12, 13);
SoftwareSerial ArduinoComm(A0, A1);

// ----- Stepper -----
#define stepsPerRev 2048
#define movementSteps 100

int currentStep = 0;
Stepper stepperMotor(stepsPerRev, 8, 9, 10, 11);

// ----- Motor (H-Bridge) -----
#define motorEN 5
#define motorIN1 7
#define motorIN2 6

// ----- IR Sensors -----
#define irSensor 2  // shooter IR
#define BoxA_IR 3
#define BoxB_IR 4

bool ballDetected = false;

enum ShootState { IDLE, BACKWARD, PAUSE, FORWARD };
ShootState shootState = IDLE;

unsigned long previousTime = 0;

bool lastSensorState = HIGH;  // shooter IR
bool bluetoothConnected = false;
int healthHearts = 10;

String Question = ""; // Stores current active question text

// Master-Request & Game State Tracking
unsigned long lastPollTime = 0;
const unsigned long pollInterval = 80; 
char lastProcessedColor = '0';

int activeBallColor = 0;      // 0 = None, 1 = Red, 2 = Blue
char correctDirection = ' ';   // Stores 'R' or 'L'
char lastChosenDir = ' ';      // Tracks the user's last mechanical command ('R' or 'L')

// Custom Hearts
byte heartCharacter[8] = {
  B00000,
  B01010,
  B11111,
  B11111,
  B01110,
  B00100,
  B00000,
  B00000
};

// Timing
#define backDuration 0
#define pauseDuration 500
#define forwardDuration 175

// -------------------------------------------------------

void updateLCDDisplay();
void stopMotor();
void shoot();

void setup() {
  pinMode(motorEN, OUTPUT);
  pinMode(motorIN1, OUTPUT);
  pinMode(motorIN2, OUTPUT);
  digitalWrite(motorEN, HIGH);

  pinMode(irSensor, INPUT);
  pinMode(BoxA_IR, INPUT);
  pinMode(BoxB_IR, INPUT);

  Serial.begin(9600);
  BT.begin(9600);
  ArduinoComm.begin(9600);

  stepperMotor.setSpeed(10);

  lcd.init();
  lcd.backlight();
  lcd.createChar(0, heartCharacter);

  // Seed random generator using noise from an unconnected pin
  randomSeed(analogRead(A5));

  // Print initial state text
  lcd.setCursor(0, 0);
  lcd.print("Connect Device");
  lcd.setCursor(0, 1);
  lcd.print("Press Any Button To Start");

  BT.listen();
}

void loop() {
  
  // 1. --- Master-Request Pattern: Request color from Main Arduino ---
  if (millis() - lastPollTime >= pollInterval) {
    lastPollTime = millis();
    
    ArduinoComm.listen();   
    ArduinoComm.print('?'); 
    
    unsigned long startTime = millis();
    char incomingColor = 'X';
    
    while (millis() - startTime < 4) {
      if (ArduinoComm.available()) {
        incomingColor = ArduinoComm.read();
        break;
      }
    }
    
    BT.listen(); // Switch back to Bluetooth state immediately
    
    if (incomingColor == '0' || incomingColor == '1' || incomingColor == '2') {
      if (incomingColor != lastProcessedColor) {
        lastProcessedColor = incomingColor;
        
        if (incomingColor == '1') { // RED BALL: Multiplication
          activeBallColor = 1;
          int val1 = random(2, 10);
          int val2 = random(2, 10);
          int rightAns = val1 * val2;
          int wrongAns = rightAns + (random(0, 2) == 0 ? random(3, 6) : -random(3, 6));
          if (wrongAns == rightAns) wrongAns += 4;
          
          // Randomly decide if the right answer is Choice R or Choice L
          bool rightIsR = (random(0, 2) == 0);
          correctDirection = rightIsR ? 'R' : 'L';
          
          Question = "RED BALL: Multiplication Question Generated!\n";
          Question += String(val1) + " x " + String(val2) + " = ?\n";
          if (rightIsR) {
            Question += "-> Choice R : " + String(rightAns) + " | Choice L : " + String(wrongAns);
          } else {
            Question += "-> Choice L : " + String(rightAns) + " | Choice R : " + String(wrongAns);
          }
          
          BT.println("\n========================================");
          BT.println(Question);
          BT.println("========================================");
        } 
        else if (incomingColor == '2') { // BLUE BALL: Addition
          activeBallColor = 2;
          int val1 = random(10, 100);
          int val2 = random(10, 100);
          int rightAns = val1 + val2;
          int wrongAns = rightAns + (random(0, 2) == 0 ? random(5, 12) : -random(5, 12));
          if (wrongAns == rightAns) wrongAns += 10;
          
          // Randomly decide if the right answer is Choice R or Choice L
          bool rightIsR = (random(0, 2) == 0);
          correctDirection = rightIsR ? 'R' : 'L';
          
          Question = "BLUE BALL: Addition Question Generated!\n";
          Question += String(val1) + " + " + String(val2) + " = ?\n";
          if (rightIsR) {
            Question += "-> Choice R : " + String(rightAns) + " | Choice L : " + String(wrongAns);
          } else {
            Question += "-> Choice L : " + String(rightAns) + " | Choice R : " + String(wrongAns);
          }
          
          BT.println("\n========================================");
          BT.println(Question);
          BT.println("========================================");
        }
        else if (incomingColor == '0') {
          // FIX: Do NOT clear activeBallColor or correctDirection here anymore!
          // Let the question variables persist until the user shoots.
        }
      }
    }
  }

  // 2. --- Local IR Sensor Logic ---
  bool sensorState = digitalRead(irSensor);
  if (sensorState == LOW) {
    ballDetected = true;
  }

  if (sensorState != lastSensorState) {
    ArduinoComm.print(sensorState); 
    lastSensorState = sensorState;
  }

  // 3. --- Bluetooth Command Processing ---
  if (BT.available()) {
    char cmd = BT.read();
    if (cmd == '\r' || cmd == '\n' || cmd == ' ') return;

    if (!bluetoothConnected) {
      bluetoothConnected = true;
      lcd.clear(); 
      updateLCDDisplay();
    }
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

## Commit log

2026-06-11 Add files via upload
    Final Version of The Wiring Diagram
    [System Wiring Diagram.fzz]
2026-06-11 Rename System Wiring Diagram.fzz to electrical/System Wiring Diagram.fzz
    [System Wiring Diagram.fzz]
2026-06-11 Add files via upload
    Final Version of Arduinoes Code
